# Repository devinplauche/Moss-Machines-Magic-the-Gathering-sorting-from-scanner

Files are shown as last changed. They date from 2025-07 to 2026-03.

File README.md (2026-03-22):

# Moss Machine - Open Source Magic: The Gathering - MTG - Sorting & Recognition

<p align="center">
  
</p>

Welcome to the Moss Machine project! This open-source initiative provides a comprehensive system for automating the sorting, recognition, and management of Trading Card Game (TCG) cards.

Current runtime note: `Current-version/optimized_scanner.py` is configured for **Magic: The Gathering only**.

Project layout reference: see `docs/PROJECT_STRUCTURE.md` for the permanent vs one-time script organization.

---

### Overview

The Moss Machine combines perceptual hash-based computer vision, multi-threaded processing, and hardware integration to create a high-performance, scalable card sorting solution. Whether you're a collector, player, or developer, this project offers tools and guidance to build your own automated card sorting system with speeds capable of processing cards in under 2 seconds per scan.

---

## Features

- **Open Source & Community Driven**  
  Fully open source code with transparent development. Contributions and modifications are encouraged—please credit the original source when creating derivatives.

- **Multi-Game Support**  
  - Supports **317 different trading card games** from a unified SQLite database
  - Includes Magic: The Gathering, Pokemon, Yu-Gi-Oh!, Flesh and Blood, Lorcana, and 300+ more
  - Filterable by game, set, rarity, and foil type for precise scanning
  - Automatic database download from server if not found locally

- **High-Performance Recognition Engine**  
  - **Perceptual hashing (pHash)** with 256-bit hash using 16x16 hash size for robust image matching
  - **RGB channel separation** - computes separate hashes for Red, Green, and Blue channels for improved accuracy
  - **Multi-threaded scanning** - parallel processing across games with 8 worker threads by default
  - **Early termination** - stops scanning immediately when exact match (distance = 0) is found
  - **Hash caching** - optional in-memory cache for popular games (Magic, Pokemon, Yu-Gi-Oh) for faster repeat scans
  - **Adaptive threshold scanning** - progressive tightening from strict to relaxed thresholds
  - **Quick distance pre-filtering** - rejects bad matches early using single-channel checks
  - **Hamming distance** calculation for fast hash comparison
  - **Average scan time** -: ~2 seconds per card across 317 games

- **Advanced Image Processing**  
  - **OpenCV-based** card detection with contour finding and perspective correction
  - **Automatic card orientation** - handles cards at any angle with 4-point perspective transform
  - **Region-based hashing** - uses top-left 745x745px crop for consistent hash generation
  - **VL6180X ToF sensor integration** - hardware distance sensing for precise Z-axis control during pickup/release
  - **Real-time camera feed processing** with automatic card detection

- **Flexible Sorting Modes**  
  - **Color sorting** - White, Blue, Black, Red, Green, Multicolor, Colorless, Land (Basic/Nonbasic)
  - **Mana value (CMC)** - Bins from 1-8+ with overflow handling
  - **Set code** - Sort by expansion/set with token detection
  - **Price-based** - 14 price brackets from $0.02 to $128+ with configurable thresholds
  - **Card type** - Creature, Artifact, Enchantment, Instant, Sorcery, Planeswalker, Battle, Land, Token
  - **Alphabetical (A-Z)** - First letter sorting with 0-9 bin for numbers/symbols
  - **Rarity** - Common, Uncommon, Rare, Mythic, Special, Bonus, Promo
  - **Finish** - Foil, Nonfoil, Both (for cards with multiple finishes)
  - **Buy mode** - Custom price threshold for purchase evaluation

- **Hardware Integration**  
  - **Arduino Mega control** via serial communication (PySerial)
  - **3-axis stepper motor control** (X, Y, Z axes plus dual E-motors for coordinated movement)
  - **Endstop sensors** on all 6 positions (X/Y/Z min/max) for safety and homing
  - **Dual vacuum system** - separate pickup and release control
  - **LED lighting control** for optimal camera visibility
  - **16x2 LCD display** (I2C) for real-time machine status
  - **34-tray sorting system** with configurable tray assignments
  - **Automatic homing and calibration** with configurable course correction
  - **Overflow tray (34)** and reject bin (33) with automatic routing
  - **Configurable parameters**: pickup/drop distances, movement speeds, thresholds, calibration multipliers
  - **Safety features**: endstop monitoring, retry logic (10 attempts), timeout handling
  - **Start/Stop machine states** - prevents accidental movements during parameter changes

- **GUI Control Interface**  
  - **Enhanced Tkinter GUI** with tabbed interface (Scanner, Arduino, Export)
  - **Live camera feed** display with real-time card detection overlay
  - **Manual and auto-scan modes** with configurable cooldown
  - **Arduino monitoring** - real-time sensor data display (range, endstops, motor states)
  - **Motor control panel** - manual control of X, Y, Z, E0, E1 motors
  - **Parameter upload/fetch** - live parameter editing and synchronization
  - **CSV export** - scan history with auto-export option
  - **Inventory tracking** - reject duplicate cards automatically
  - **Game/Set/Rarity/Foil filters** with dropdown selection
  - **Status logging** with color-coded messages

- **Performance & Reliability**  
  - **Detailed statistics** - tracks scans, total time, average time, cards checked, cache hits
  - **Retry mechanisms** - up to 10 pickup attempts with distance sensor verification
  - **Periodic homing** - automatic recalibration every N cards (configurable)
  - **Course correction** - fine-tune X/Y positioning to prevent drift
  - **Thread-local database connections** for safe multi-threading
  - **Confidence scoring** - percentage-based match quality with configurable minimum thresholds
  - **Duplicate detection** via inventory file tracking

- **Command Line Interface**  
  - Interactive mode with sorting menu
  - Realtime webcam mode for continuous scanning
  - Single-image scanning with detailed match output
  - Game/set/rarity/foil filtering via command-line arguments
  - List all games, sets, rarities, and foil types
  - Adjustable threshold and top-N results
  - Cache preloading option
  - Serial port and baud rate configuration

- **Configurable & Extensible**  
  - All movement parameters configurable (speeds, distances, calibration multipliers)
  - Adjustable hash matching thresholds (default: 10, lower = stricter)
  - Customizable tray assignments with automatic overflow
  - Price threshold configuration for buy mode
  - Worker thread count adjustable (default: 8)
  - Scan cooldown adjustable (default: 2.0 seconds)
  - Game-specific foil type and rarity detection

- **Technology Stack**  
  - **Python 3**: OpenCV (cv2), ImageHash, Pillow (PIL), PySerial, NumPy, SQLite3, Threading, Tkinter
  - **Database**: Unified SQLite database with 317 game-specific card tables, games table, sets table, and others (future development)
  - **Arduino**: C++ firmware for Mega 2560, Stepper motor control, I2C LCD, VL6180X ToF sensor (Adafruit library)
  - **Hardware**: RAMPS 1.4 board, A4988 stepper drivers, NEMA 17 motors, endstop switches, vacuum pumps, LED strips  

---

## System Architecture

### Software Components

1. **optimized_scanner.py** - Core recognition engine
   - `OptimizedCardScanner` class with multi-threaded game scanning
   - Perceptual hash computation and comparison
   - Database connection pooling (thread-local connections)
   - Adaptive threshold scanning
   - Serial communication with Arduino
   - Real-time webcam mode
   - Command-line interface with extensive filtering options

2. **gui_interface_enhanced.py** - GUI control interface
   - Tabbed interface (Scanner, Arduino, Export)
   - Live camera feed with card detection visualization
   - Arduino parameter management and monitoring
   - CSV export with scan history
   - Game/Set/Rarity/Foil filtering
   - Auto-scan and manual scan modes

3. **Main.ino** - Arduino firmware
   - 3-axis stepper motor control (X, Y, Z + E0, E1 dual drive)
   - VL6180X ToF sensor integration for distance measurement
   - Endstop monitoring (6 endstops: X/Y/Z min/max)
   - Dual vacuum system control
   - LCD status display (16x2 I2C)
   - Serial command parser with start/end markers
   - 34-tray coordinate system with automatic routing
   - Homing and calibration routines
   - State machine (Stopped/Started) for safe operation

### Database Structure

- **unified_card_database.db** (SQLite)
  - `games` table: 317 games with ID, name, display_name, total_cards
  - `cards_*` tables: One table per game (e.g., cards_magic, cards_pokemon, cards_yugioh)
  - `sets` table: Set information per game with set codes and card counts
  - Card columns: unique_id, product_id, set_code, rarity, name, series, number, prices (low/mid/high/market/imputed), subTypeName (foil type), has_image, phash (r_phash, g_phash, b_phash), extCardType
  - Optional: SKU columns (111 columns for condition/language/printing combinations)

### Hardware Components

- **Arduino Mega 2560** - Main controller
- **RAMPS 1.4** - Motor driver board
- **A4988 Stepper Drivers** (5x) - Motor control
- **NEMA 17 Stepper Motors** (5x) - X, Y, Z, E0, E1 axes
- **VL6180X ToF Sensor** - Distance measurement (I2C)
- **Endstop Switches** (6x) - Limit switches for safety
- **16x2 LCD Display** (I2C) - Status display
- **Vacuum Pumps** (2x) - Card pickup and release
- **LED Strip** - Lighting for camera
- **Webcam** - Card image capture

---

## Quick Start

### Software Setup

1. **Install Python dependencies:**
   ```bash
   pip install opencv-python pillow imagehash pyserial numpy
   ```

2. **Database:**
   - Place `unified_card_database.db` in the project directory
   - Or let the scanner auto-download from configured server URLs

3. **Run the scanner:**
   ```bash
   # Command-line mode (single image)
   python optimized_scanner.py card.jpg --cache

   # Interactive mode with Arduino
   python optimized_scanner.py --interactive --serial-port COM3

   # Realtime webcam mode
   python optimized_scanner.py --realtime --cache

   # GUI mode
   python gui_interface_enhanced.py
   ```

### Arduino Setup

1. **Install Arduino libraries:**
   - LiquidCrystal_I2C
   - Adafruit_VL6180X
   - Wire (built-in)
   - Stepper (built-in)

2. **Upload Main.ino** to Arduino Mega 2560

3. **Connect hardware:**
   - RAMPS 1.4 to Mega
   - Stepper motors to X, Y, Z, E0, E1 outputs
   - Endstops to min/max pins
   - VL6180X sensor to I2C (SDA/SCL)
   - LCD to I2C
   - Vacuum relays to pins 9 & 10
   - LED to pin 8

4. **Configure serial port** in Python scripts (default: COM3, 9600 baud)

### Usage Examples

```bash
# List all supported games
python optimized_scanner.py --list-games

# List sets for Magic (game ID 167)
python optimized_scanner.py --list-sets 167

# Scan a card, filter to Magic only
python optimized_scanner.py card.jpg -g Magic --cache

# Scan with set filter (Alpha and Beta)
python optimized_scanner.py card.jpg -s LEA -s LEB

# Filter by foil type and rarity
python optimized_scanner.py card.jpg -f Foil -r M -r R

# Adaptive scan with relaxed thresholds
python optimized_scanner.py card.jpg -t 20 --min-confidence 70
```

---

## Configuration

### Scanner Parameters (optimized_scanner.py)

- `max_workers`: Thread pool size (default: 8)
- `cache_enabled`: Enable in-memory hash caching (default: True)
- `threshold`: Match threshold, lower = stricter (default: 10)
- `top_n`: Number of top matches to return (default: 10)
- `min_confidence`: Minimum confidence % for Method 1 (default: 85.0)
- `scan_cooldown`: Seconds between auto-scans (default: 2.0)

### Arduino Parameters (Main.ino)

- `Xcal`, `Ycal`, `Zcal`: Movement calibration multipliers (350, 475, 140)
- `speed`: XY movement speed in microseconds (default: 700)
- `zspeed`, `zespeed`: Z-axis speeds (75, 120)
- `initial_pickup_distance`: Z distance to pickup position (6000 steps)
- `initial_drop_distance`: Z distance to drop position (4000 steps)
- `pickup_threshold`: Distance threshold for successful pickup (40mm)
- `release_threshold`: Distance threshold for successful release (40mm)
- `HCC`: Homing cycle count - rehome every N cards (default: 10)
- `XCourseCorrection`, `YCourseCorrection`: Fine-tune positioning (0, 1)

### Tray Layout (Main.ino)

- **Trays 1-32**: Configurable card bins
- **Tray 33**: RejectCard bin (reserved)
- **Tray 34**: OverflowTray (reserved)
- Coordinate arrays: `X[6][5]` and `Y[4][7]` define physical tray positions

---

## Pictures


---

### Disclaimer

- The project is open source and may evolve significantly over time.  
- All code is thoroughly tested but may require calibration based on your hardware setup.  
- Use caution—never put valuable cards in the machine without testing.  
- If you modify or create your own variations, please credit the original source.

---

## Build Your Own

### Get Started
- All necessary files, including code, 3D print files, and hardware schematics, are available in this repository.
- Follow the detailed instructions within the Discord under #assembly

---

## Legal & Usage Notice

**Disclaimer:**  
This system is intended for hobbyist and educational use. Always test with non-valuable cards first. Handle valuable or rare cards with care—never trust automated sorting in critical scenarios. The project is open source; use at your own risk.

---

## Connect with Us & Follow

| Discord Logo | Reddit Logo | GitHub Logo |
|:---:|:---:|:---:|
| **Join our Discord:**<br>[https://discord.gg/2gNWpV6UjW](https://discord.gg/2gNWpV6UjW) | **Reddit:**<br>[r/MossMachine](https://www.reddit.com/r/MossMachine/) | **Repository:**<br>[GitHub](https://github.com/KairiCollections/Moss-Machine---Magic-the-Gathering-recognition-and-sorting-machine) |

---

## Support
Help keep my motivation and my wife less annoyed with the machine's existence
- Patreon - https://www.patreon.com/KairiCollections
- By me a coffee - https://www.buymeacoffee.com/KairiCollections
- Ko-fi - http://ko-fi.com/kairiskyewillow

Other non-related support:
- https://www.etsy.com/shop/KairiCollections

---

## Acknowledgments & License

This project is licensed under the **Creative Commons Attribution-NonCommercial-ShareAlike 4.0 International License (CC BY-NC-SA 4.0)**.  
Please give credit to the original authors when creating derivatives.

---

**Happy Sorting!**

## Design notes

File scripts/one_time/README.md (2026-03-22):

# One-time Scripts

This folder contains scripts and artifacts used for manual debugging, migration, and investigation.

These files are intentionally separated from runtime scanner code so junior engineers can quickly identify what is safe to run in production flows.

Current contents:

- `check_db.py`
- `check_real_db.py`
- `debug_hisokas.py`
- `explore_db.py`
- `debug_scan_with_custom.json`
- `debug_scan_without_custom.json`

Guideline:

- If a script is only used for a one-off task or local debugging, place it here.
- If a script is imported by runtime code or CI tests, keep it in a permanent runtime location.

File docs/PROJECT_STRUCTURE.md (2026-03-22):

# Project Structure

This repository is organized by runtime permanence and ownership.

## Core Runtime (Permanent)

- `Current-version/optimized_scanner.py`: Main scanner runtime and CLI.
- `Current-version/scanner_modules/image_preprocessing.py`: Image-path validation and reusable crop/warp helpers.
- `Current-version/card_filter.py`: Metadata pre-filtering logic.
- `Current-version/card_collection_manager.py`: Collection persistence/export.
- `Current-version/gui_interface_enhanced.py`: GUI controller and scanner orchestration.
- `Current-version/plugins/`: Runtime plugin interfaces and stubs.
- `Current-version/recognition_data/`: pHash databases and scan metadata assets.

## Test Suite (Permanent)

- `test_debug_crops_regression.py`: Regression tests for missing-file behavior, debug crop names, and `IMG_3490.jpg` handling.
- `test_card_filter.py`, `test_hisokas.py`, `test_scanner.py`, `test_system_complete.py`: Existing tests and integration checks.

## One-time and Exploratory Assets

- `scripts/one_time/`: ad hoc scripts and JSON snapshots used for investigation or manual maintenance.
- `Current-version/ai-slop/`: one-off data generation, diagnostics, and historical pHash maintenance scripts.

## Working Data

- `Collection/`: scanner input/output artifacts.
- `Current-version/debug_crops/`: diagnostic crops used for scanner regression and tuning.

## Naming and Placement Rules

- Put runtime logic used by scanner/GUI in `Current-version/`.
- Put reusable helpers in `Current-version/scanner_modules/`.
- Put throwaway scripts or migration jobs in `scripts/one_time/`.
- Add or update tests in the repository root as `test_*.py`.

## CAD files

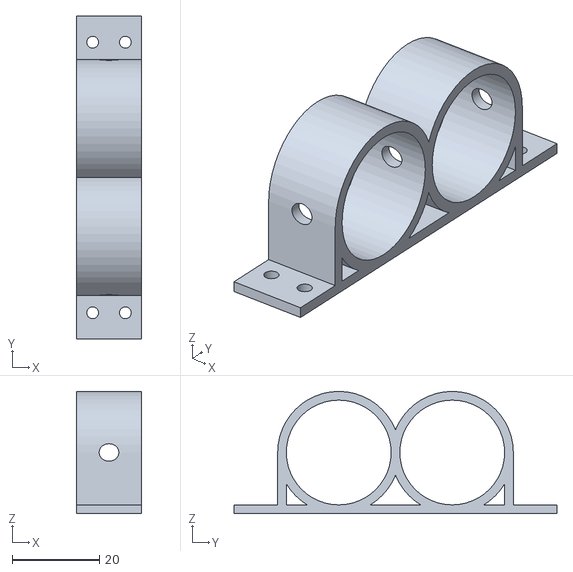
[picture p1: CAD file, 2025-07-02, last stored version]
3D print/Electrical/Din rail options/Double vacuum mount.stl
15.0 x 74.0 x 28.0

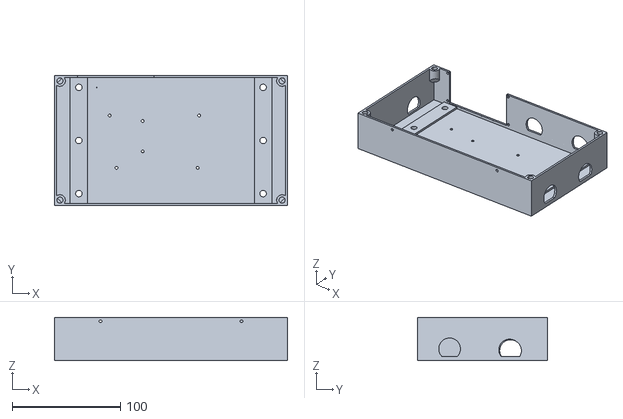
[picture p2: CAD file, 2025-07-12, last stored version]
3D print/Electrical/Electrical box/Electrical box.stl
215.0 x 120.0 x 39.8

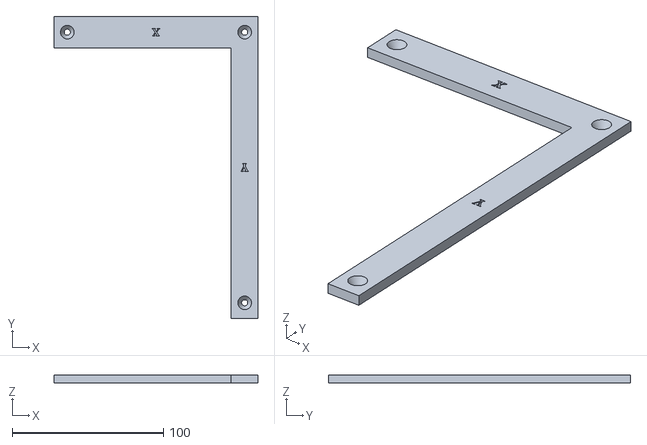
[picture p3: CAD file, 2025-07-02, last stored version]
3D print/Trays/Corner 3.stl
135.0 x 200.0 x 5.00

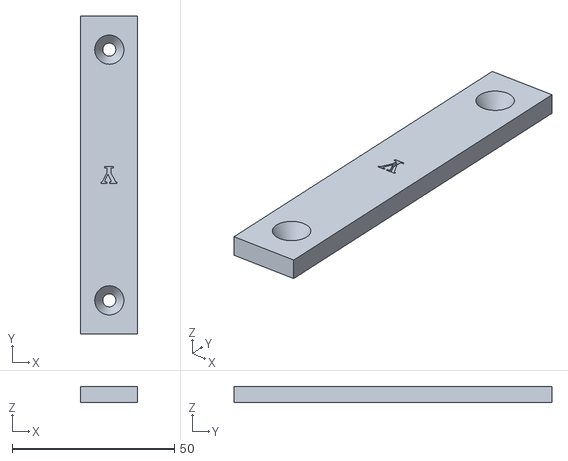
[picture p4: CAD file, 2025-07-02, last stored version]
3D print/Trays/Y space - Print 2.stl
17.7 x 98.0 x 5.00

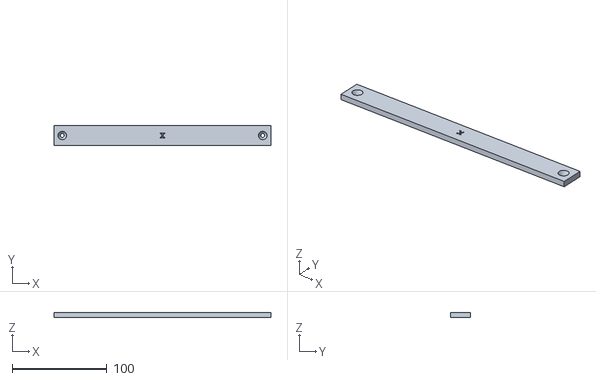
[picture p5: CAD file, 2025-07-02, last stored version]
3D print/Trays/X space - Print 2.stl
229.5 x 20.8 x 5.00

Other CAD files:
3D print/Trays/Corner 2.stl
3D print/Trays/Corner 1.stl
3D print/Trays/Corner 4.stl

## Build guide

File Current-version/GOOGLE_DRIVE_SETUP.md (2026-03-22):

# Google Drive Batch Scanning - Setup & Usage Guide

## Overview

This system integrates Google Drive with the MTG card scanner, allowing you to:
- Authenticate with Google Drive
- List all images in a specified folder
- Download images locally
- Scan each card automatically
- Export results to CSV/JSON

## Prerequisites

### 1. Install Required Python Packages

```bash
pip install google-auth-oauthlib google-auth-httplib2 google-api-python-client
```

### 2. Set Up Google Drive API Credentials

#### Step 1: Create a Google Cloud Project
1. Visit [Google Cloud Console](https://console.cloud.google.com/)
2. Create a new project or select an existing one
3. Enable the **Google Drive API**:
   - Click "APIs & Services" → "Library"
   - Search for "Google Drive API"
   - Click it and press "Enable"

#### Step 2: Create OAuth 2.0 Credentials
1. Go to "APIs & Services" → "Credentials"
2. Click "Create Credentials" → "OAuth 2.0 Client ID"
3. Choose "Desktop application"
4. Click "Create"
5. Click the download icon (appears when hovering over your credential)
6. Save the file as `credentials.json` in the `Current-version/` directory

#### Step 3: First Run Authentication
The first time you run a scan command, it will:
1. Open a browser window asking for Google Drive access
2. Create a local token file (`google_drive_token.pickle`) for future use
3. Proceed with scanning

## Quick Start

### Basic Usage

```bash
cd Current-version
python scan_google_drive.py --folder-url "https://drive.google.com/drive/folders/1g_WOPFaYGWfiKbtLqO3aZAOEQOWnxJLc"
```

### With Output Files

```bash
python scan_google_drive.py \
    --folder-url "https://drive.google.com/drive/folders/1g_WOPFaYGWfiKbtLqO3aZAOEQOWnxJLc" \
    --output-csv scan_results.csv \
    --output-json scan_results.json
```

### Keep Downloaded Images

```bash
python scan_google_drive.py \
    --folder-url "1g_WOPFaYGWfiKbtLqO3aZAOEQOWnxJLc" \
    --keep-local
```

### Using Filters

```bash
python scan_google_drive.py \
    --folder-url "1g_WOPFaYGWfiKbtLqO3aZAOEQOWnxJLc" \
    --set-filter "MIR" \
    --foil-filter "Non Foil" \
    --output-csv results.csv
```

## Command Line Options

```
--folder-url URL              Google Drive folder URL or folder ID [REQUIRED]
--threshold N                 Match threshold, 0-255 (default: 40, lower = stricter)
--top-n N                     Number of top matches to return (default: 10)
--output-csv PATH             Save results as CSV file
--output-json PATH            Save results as JSON file
--set-filter CODE             Filter by card set code (e.g., "MIR", "TSR")
--foil-filter TYPE            Filter by foil type (e.g., "Foil", "Non Foil")
--rarity-filter RARITY        Filter by rarity (e.g., "Rare", "Uncommon")
--download-dir PATH           Directory for downloaded images (default: google_drive_downloads)
--keep-local                  Keep downloaded images after scanning (default: delete)
--force-reauth                Force re-authentication to Google Drive
--max-workers N               Parallel workers for processing (default: 4)
--db-path PATH                Path to card database (default: unified_card_database.db)
--verbose                     Verbose output
--help                        Show all options
```

## Python API Usage

If you want to integrate this into your own Python code:

```python
from optimized_scanner import OptimizedCardScanner
from google_drive_scanner import BatchGoogleDriveScanner

# Initialize scanner
scanner = OptimizedCardScanner()

# Initialize batch processor
batch = BatchGoogleDriveScanner(scanner, download_dir="my_downloads")

# Force authentication on first run
# batch.gdrive_client.authenticate()

# Scan folder
folder_url = "https://drive.google.com/drive/folders/1g_WOPFaYGWfiKbtLqO3aZAOEQOWnxJLc"
results, stats = batch.scan_folder(
    folder_url_or_id=folder_url,
    threshold=40,
    output_csv="results.csv",
    output_json="results.json",
    keep_local_copies=False
)

# Access results
for result in results:
    if result.get('match_found'):
        print(f"Found: {result['card_name']} ({result['set']})")
    else:
        print(f"No match: {result['source_file']}")

# Access stats
print(f"Matches found: {stats['matches_found']} / {stats['processed']}")
```

## Output Format

### CSV Results
Columns include:
- `source_file`: Original filename from Google Drive
- `card_name`: Recognized card name
- `set`: Card set code
- `product_id`: Product ID from database
- `distance`: Hash distance (0 = exact match)
- `confidence`: Confidence percentage (0-100)
- `rarity`: Card rarity
- `foil_type`: Foil type (Foil/Non-Foil/etc)
- `number`: Card number in set
- `status`: success/error
- `all_matches`: Top 3 matching cards (JSON)

### JSON Results
```json
{
  "timestamp": "2026-03-21 14:30:45",
  "results": [
    {
      "source_file": "scan_001.jpg",
      "card_name": "Black Lotus",
      "set": "BET",
      "distance": 0,
      "confidence": 100.0,
      "status": "success"
    }
  ],
  "stats": {
    "total_files": 50,
    "successful_scans": 48,
    "matches_found": 42
  }
}
```

## Troubleshooting

### Authentication Issues

**Q: "Credentials file not found"**
- Make sure `credentials.json` is in the `Current-version/` directory
- See setup step 2 above for how to download credentials

**Q: "Token refresh failed"**
- Delete `google_drive_token.pickle` and run with `--force-reauth`
- You'll need to re-authenticate in the browser

### Scanning Issues

**Q: "No images found in folder"**
- Verify the folder URL/ID is correct
- Ensure the folder actually contains image files (jpg, png, bmp, etc)
- Check that sharing permissions allow your account to view the folder

**Q: "Downloaded image can't be scanned"**
- Verify the image is a valid card photo
- Try reducing the `--threshold` value for more lenient matching
- Check that the database file exists: `unified_card_database.db`

**Q: "Process is slow"**
- Increase `--max-workers` (be careful not to exceed API rate limits)
- Use `--set-filter` to narrow down the search space
- Consider reducing `--top-n` if you only need 1-2 matches

### Google Drive API Issues

**Q: "Rate limit exceeded"**
- Wait a few minutes before running again
- Reduce `--max-workers` to lower concurrency
- Google Drive API has strict rate limiting for free accounts

**Q: "Permission denied"**
- Verify you have access to the Google Drive folder
- Try removing `google_drive_token.pickle` and re-authenticating
- Check Google Cloud Console project permissions

## Advanced Usage

### Batch Processing Multiple Folders

```bash
#!/bin/bash
# Process multiple folders
for folder_id in "1g_WOPFaYGWfiKbtLqO3aZAOEQOWnxJLc" "2h_XXXxxxGWfiKbtLqO3aZAOEQOWnxJLd"; do
  python scan_google_drive.py \
    --folder-url "$folder_id" \
    --output-csv "results_${folder_id}.csv"
done
```

### Combining Results

```python
import pandas as pd
import glob

# Combine all CSV results
all_results = []
for csv_file in glob.glob("results_*.csv"):
    df = pd.read_csv(csv_file)
    all_results.append(df)

combined = pd.concat(all_results, ignore_index=True)
combined.to_csv("all_results_combined.csv", index=False)
print(f"Total cards scanned: {len(combined)}")
print(f"Matches found: {combined[combined['match_found'] == True].shape[0]}")
```

## Performance Tips

1. **Threshold Tuning**: 
   - Lower values (10-30): Stricter matching, fewer false positives
   - Higher values (60-100): More lenient, better for low-quality images

2. **Parallel Processing**:
   - Default `--max-workers 4` is usually safe
   - Increase to 8-16 for VPS/server environments
   - Keep ≤4 for local machines to avoid resource exhaustion

3. **Filtering**:
   - Use `--set-filter` when scanning specific sets
   - Dramatically speeds up search when you know the set

4. **Network**:
   - Faster internet = faster downloads
   - Run on same network as scanner if possible

## Support

For issues or questions:
1. Check the troubleshooting section above
2. Run with `--verbose` for detailed output
3. Check that all dependencies are installed: `pip list | grep google`

## Files

- `google_drive_scanner.py`: Core Google Drive integration library
- `scan_google_drive.py`: CLI command-line interface
- `credentials.json`: Your Google Drive API credentials (create in setup)
- `google_drive_token.pickle`: Cached authentication token (auto-created)
- `google_drive_downloads/`: Directory where images are downloaded (default)

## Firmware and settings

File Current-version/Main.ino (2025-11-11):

#include <LiquidCrystal_I2C.h>
#include <Stepper.h>
#include <Wire.h>
#include "Adafruit_VL6180X.h"

//Pin Definitions for hardware control
enum Pins { 
    Zmin = 18, Xmin = 3, Ymin = 14, Xmax = 2, Ymax = 15, Zmax = 19, //Endstops
    Lights = 8, Vacuum1 = 9, Vacuum2 = 10, //Vacuums: Pickup/Release respectively
    Xenable = 38, Yenable = 56, Zenable = 62, E0enable = 24, E1enable = 30, //Motors
    Xstep = 54, Ystep = 60, Zstep = 46, E0step = 26, E1step = 36, //Stepper Controls
    Xdir = 55, Ydir = 61, Zdir = 48, E0dir = 28, E1dir = 34 //Directions
};

//Initialize sensor and display objects
Adafruit_VL6180X vl = Adafruit_VL6180X();  //VL6180X distance sensor object
LiquidCrystal_I2C lcd(0x27, 16, 2);        //LCD for user feedback

//Flags and control variables
boolean newData = false, readInProgress = false, newDataFromPC = false;
boolean atHomePosition = true;  //Track if machine is at home position (safe for parameter changes)
boolean machineStarted = false; //Track if machine is in Started state (accepting tray commands)
byte bytesRecvd = 0, PickupRetry;
const byte numChars = 64, buffSize = 40;                                               //Buffer sizes for serial communication
const char startMarker = '<', endMarker = '>';                                         //Start/End markers for data communication
char inputBuffer[buffSize], messageFromPC[buffSize] = { 0 }, receivedChars[numChars];  //Buffers for data

//Timers and counters
float timeoutcount = 0;
const float timeout = 10;

//Coordinates and distance tracking arrays
const char* MatchingValues[] = {"RejectCard", "tray1", "tray7", "tray14", "tray18","tray25", "tray26", "tray27", "tray28", "tray29", "tray30", "tray31", "tray32"};
const int loopStart[] = {33, 1, 7, 14, 18, 25, 26, 27, 28, 29, 30, 31, 32};
const int loopEnd[] = {33, 6, 13, 17, 24, 25, 26, 27, 28, 29, 30, 31, 32};
boolean match = 0;
const int xOffsets[6] = {-3, -2, -1, 1, 2, 3}; const int yOffsets[4] = {-2, -1, 1, 2}; //Arrays for X/Y coordinate movements
const short X[6][5]={{31,27,21,28,32},{23,11,9,12,24},{17,5,1,6,18},{19,7,2,8,20},{25,13,10,14,26},{33,29,22,30,34}}; //Array for X trays
const short Y[4][7]={{32,24,18,16,20,26,34},{28,12,6,4,8,14,30},{27,11,5,3,7,13,29},{31,23,17,15,19,25,33}}; //Array for Y trays
short CountArray[35], upcount; //Array is for keeping track of how many cards have been moved to each tray
String AssignedTrayValue[35], Tempval1; //Array for keeping try of tray assignments
uint8_t range[6]; //Range readings from VL6180X sensor

//Endstop tracking variables (limits of movement for each axis)
byte X_ENDSTOP_MIN, Y_ENDSTOP_MIN, Z_ENDSTOP_MIN, X_ENDSTOP_MAX, Y_ENDSTOP_MAX, Z_ENDSTOP_MAX;

//Movement parameters (calibration and speed settings)
short initial_pickup_distance = 6000, initial_drop_distance = 4000;  //Intial movement distances
short Xcal = 350, Ycal = 475, Zcal = 140;                            //Movement multipliers
short speed = 700, zspeed = 75, zespeed = 120;                       //Movement speed (Higher number=slower speed)
short pickup_threshold = 40, release_threshold = 40;                 //Thresholds for pickup/release conditions
short HCC = 10, YCourseCorrection = 1, XCourseCorrection = 0;        //Cycles until rehome and course correction variables

void setup() {
  byte pins[] = { Xstep, Ystep, Zstep, E0step, E1step, Xdir, Ydir, Zdir, E0dir, E1dir, Xenable, Yenable, Zenable, E0enable, E1enable, Vacuum1, Vacuum2, Lights};
  for (byte pin : pins) { pinMode(pin, OUTPUT); }  //Set all pins as outputs
  
  // Motors enabled (LOW), vacuums off (LOW), lights ON (HIGH) by default
  digitalWrite(Xenable, LOW);    //X motor enabled
  digitalWrite(Yenable, LOW);    //Y motor enabled  
  digitalWrite(Zenable, LOW);    //Z motor enabled
  digitalWrite(E0enable, LOW);   //E0 motor enabled
  digitalWrite(E1enable, LOW);   //E1 motor enabled
  digitalWrite(Vacuum1, LOW);    //Vacuum1 off
  digitalWrite(Vacuum2, LOW);    //Vacuum2 off
  digitalWrite(Lights, HIGH);    //Lights on by default

  Serial.begin(9600);                        //Begin serial connection
  digitalWrite(13, HIGH);                    //Turn on the onboard LED for debugging
  while (!Serial) { delay(10); }             //Wait for serial to be ready
  Serial.println("Adafruit VL6180x test!");  //Print sensor initialization message
  while (!vl.begin()) {
    Serial.println("Failed to find sensor");
    PrintLCD("Failed to find ", "ToF sensor"); //Display error on LCD if sensor not found
    delay(1000);
  }  
  Serial.println("Sensor found!");PrintLCD("ToF sensor", "found");
  Homemachine(); //Call Homemachine to calibrate the system
  delay(100);Serial.println("<Arduino is ready>");
}

void loop() {
  uint8_t status = vl.readRangeStatus();
  if (AssignedTrayValue[34] != "OverflowTray") {AssignedTrayValue[34] = "OverflowTray";} //Assign some initial tray values that are reserved
  if (AssignedTrayValue[33] != "RejectCard") {AssignedTrayValue[33] = "RejectCard";}
  getDataFromPC(); //Retrieve data from PC

  //Check sensor error status and handle errors accordingly
  if (status == VL6180X_ERROR_NONE) {ReadRange(1); Serial.print("Range: "); Serial.println((range[0] + range[1]) / 2);
  } else {PrintLCD("ToF: No range", " ");}
  switch (status) { //Various errors that can happen with the range sensor
    case VL6180X_ERROR_SYSERR_1 ... VL6180X_ERROR_SYSERR_5: Serial.println("System error"); break;
    case VL6180X_ERROR_ECEFAIL: Serial.println("ECE failure"); PrintLCD("ECE failure", " ");break;
    case VL6180X_ERROR_NOCONVERGE: Serial.println("No convergence"); PrintLCD("No convergence", " "); break;
    case VL6180X_ERROR_RANGEIGNORE: Serial.println("Ignoring range"); PrintLCD("Ignoring range", " "); break;
    case VL6180X_ERROR_SNR: Serial.println("Signal/Noise error"); PrintLCD("Signal/Noise", "error"); break;
    case VL6180X_ERROR_RAWUFLOW: Serial.println("Raw reading underflow"); PrintLCD("Raw reading", "underflow"); break;
    case VL6180X_ERROR_RAWOFLOW: Serial.println("Raw reading overflow"); PrintLCD("Raw reading", "overflow"); break;
    case VL6180X_ERROR_RANGEUFLOW: Serial.println("Range reading underflow"); PrintLCD("Range reading", "underflow"); break;
    case VL6180X_ERROR_RANGEOFLOW: Serial.println("Range reading overflow"); PrintLCD("Range reading", "overflow"); break;
    default: break;
  }
  lcd.init();lcd.backlight();lcd.setCursor(0, 0); //Initialize LCD and turn on the backlight
  ReadEndstops(); //Read endstop values 
  //if(Y_ENDSTOP_MIN==0||Z_ENDSTOP_MIN==0||X_ENDSTOP_MAX==0){PrintLCD("Endstop reached"," ");STOP==1;delay(100);}
  PrintLCD("Ready", " "); //Display "Ready" message on LCD 
  Tempval1 = Serial.readString();delay(10); //read any available data from the serial buffer
  if (Tempval1 != "") {
    PrintLCD("Received: ", Tempval1); //Display the received data on the LCD
    ReadRange(1);DetermineAction(); //Decide what action to take based on received data
    Serial.println("<Arduino is ready>");
    timeoutcount = 0; //Reset timeout counter
  }  
  //timeoutcount++;if(timeoutcount>=timeout){Tray(34);Serial.println("<Arduino is ready>");timeoutcount=0;}
  //Serial.println(timeoutcount);

  //Reset flags
  Tempval1 = "";messageFromPC == "";bytesRecvd == 0;newData = false;readInProgress = false;newDataFromPC = false;
}  

void getDataFromPC() {
  if (Serial.available() > 0) {
    char x = Serial.read();  //Read incoming character
    if (x == endMarker) { //End marker received
      readInProgress = false;
      newDataFromPC = true;
      inputBuffer[bytesRecvd] = 0; //null terminate input buffer 
      parseData(); //parse the received data
    }   
    if (readInProgress) {
      inputBuffer[bytesRecvd] = x;
      bytesRecvd++;  //Data is still being read
      if (bytesRecvd == buffSize) { bytesRecvd = buffSize - 1; } //Prevent buffer overflow
    }  
    if (x == startMarker) { //Start marker received, begin reading
      bytesRecvd = 0;
      readInProgress = true;
    }
  }
}  

//Parse the received data from the buffer
void parseData() {
  char* strtokIndx;
  strtokIndx = strtok(inputBuffer, ",");  //Split the string by commas
  strcpy(messageFromPC, strtokIndx);      //Store the first token
  strtokIndx = strtok(NULL, ",");
  strtokIndx = strtok(NULL, ","); //Continue parsing if necessary
}

//Handle the picking process, with retries
void pick(short steps, byte Release) {PickupRetry = 0;
retrypickup:
  Move1(0, steps, zspeed);  //Move to pickup position
  if (Release == 1) {MotorsOnOff(1);delay(100);digitalWrite(Vacuum2,1);delay(300);digitalWrite(Vacuum2,0);ReadRange(3);  //Turn motors off and release card
    while ((range[2] + range[3]) / 2 < release_threshold) {digitalWrite(Vacuum2,1);delay(300);digitalWrite(Vacuum2,0);ReadRange(3);}//Check range and if card didn't drop retry
    MotorsOnOff(0);delay(100);Move1(1, steps, zespeed);} //Turn motors back on and move back up
  if (Release == 0) {digitalWrite(Vacuum1, 1);delay(500);digitalWrite(Vacuum1, 0);Move1(1, steps, zespeed);}ReadRange(3);//Vacuum to pick up card
    if (((range[2] + range[3]) / 2) > pickup_threshold) {PickupRetry++;if (PickupRetry >= 10) {StopMachine();} else {goto retrypickup;}}//If 10 retrys failed stop the machine
}  

//Homing routine to calibrate the machine
void Homemachine() {PrintLCD("Calibrating", " ");ReadEndstops();  //Read the endstop values
  if (Z_ENDSTOP_MIN == 1) {Move1(0, 800, zespeed);while (Z_ENDSTOP_MIN == 1) {Move1(1, 3, zespeed);Z_ENDSTOP_MIN = digitalRead(Zmin);}delay(200);}//calibrate z
  if (Y_ENDSTOP_MIN == 1) {Move4(1, 0, 0, 50);while (Y_ENDSTOP_MIN == 1) {Move4(0, 1, 0, 5);Y_ENDSTOP_MIN = digitalRead(Ymin);}delay(200);}//calibrate y
  if (X_ENDSTOP_MAX == 1) {Move4(1, 0, 50, 0);while (X_ENDSTOP_MAX == 1) {Move4(0, 1, 3, 0);X_ENDSTOP_MAX = digitalRead(Xmax);}delay(200);}//calibrate x
  Move1(0, 3000, zspeed); delay(200);Move4(1, 0, Xcal * 3 + 55, Ycal * 2 + 38); delay(200); //Move to home position
}  

void StopMachine() { //Stop the machine and display a message
  PrintLCD("Machine stop", "Empty and reset"); MotorsOnOff(0); while (1) { delay(10000);}
}

void ReadEndstops() { //Read the endstop sensors
  X_ENDSTOP_MIN = digitalRead(Xmin);X_ENDSTOP_MAX = digitalRead(Xmax);
  Y_ENDSTOP_MIN = digitalRead(Ymin);Y_ENDSTOP_MAX = digitalRead(Ymax);
  Z_ENDSTOP_MIN = digitalRead(Zmin);Z_ENDSTOP_MAX = digitalRead(Zmax);
}

void MotorsOnOff(boolean OnOff) { //Turns all motors on or off
  digitalWrite(Xenable, OnOff);digitalWrite(E0enable, OnOff);
  digitalWrite(Yenable, OnOff);digitalWrite(E1enable, OnOff);
  digitalWrite(Zenable, OnOff);
}

void DetermineAction() { //Figure out what to do
  // Start/Stop commands
  if (Tempval1 == "StartMachine") {
    machineStarted = true;
    Serial.println("<OK,MachineStarted>");
    PrintLCD("Machine STARTED", "Accepting cards");
    return;
  } else if (Tempval1 == "StopMachine") {
    machineStarted = false;
    Serial.println("<OK,MachineStopped>");
    PrintLCD("Machine STOPPED", "Controls enabled");
    return;
  }
  
  // Tray commands only allowed when machine is started
  for (int i = 0; i < sizeof(MatchingValues) / sizeof(MatchingValues[0]); ++i) {
    if (Tempval1 == MatchingValues[i]) {
      if (!machineStarted) {
        Serial.println("<Error,MachineNotStarted>");
        PrintLCD("Error: Stopped", "Start machine!");
        return;
      }
      match = 1; atHomePosition = false; ForLoop(loopStart[i], loopEnd[i]); atHomePosition = true; 
      break;
    }
  }
  
  // Manual controls only allowed when machine is stopped
  if (Tempval1 == "CalibrateX1" || Tempval1 == "CalibrateX2" || 
      Tempval1 == "CalibrateY1" || Tempval1 == "CalibrateY2" || 
      Tempval1 == "HomeButton") {
    if (machineStarted) {
      Serial.println("<Error,MachineStarted>");
      PrintLCD("Error: Started", "Stop machine!");
      return;
    }
  }
  
  // Calibration commands (minor movements)
  if (Tempval1 == "CalibrateX1") {Move4(0,1,5,0);
  } else if (Tempval1 == "CalibrateX2") {Move4(1,1,5,0);
  } else if (Tempval1 == "CalibrateY1") {Move4(0,0,0,5);
  } else if (Tempval1 == "CalibrateY2") {Move4(0,1,0,5);
  } else if (Tempval1 == "HomeButton") {Homemachine();atHomePosition = true;
  
  // Query sensor data
  } else if (Tempval1 == "QuerySensors") {
    ReadRange(1);
    ReadEndstops();
    String response = "<Sensors,range=";
    response += String((range[0] + range[1]) / 2);
    response += ",xmin=" + String(X_ENDSTOP_MIN);
    response += ",xmax=" + String(X_ENDSTOP_MAX);
    response += ",ymin=" + String(Y_ENDSTOP_MIN);
    response += ",ymax=" + String(Y_ENDSTOP_MAX);
    response += ",zmin=" + String(Z_ENDSTOP_MIN);
    response += ",zmax=" + String(Z_ENDSTOP_MAX);
    response += ",home=" + String(atHomePosition ? 1 : 0);
    response += ",started=" + String(machineStarted ? 1 : 0);
    response += ">";
    Serial.println(response);
  
  // Motor control commands (only when stopped)
  } else if (Tempval1.startsWith("SetMotor,")) {
    if (machineStarted) {
      Serial.println("<Error,MachineStarted>");
      return;
    }
    
    int comma1 = Tempval1.indexOf(',');
    int comma2 = Tempval1.indexOf(',', comma1 + 1);
    String motor = Tempval1.substring(comma1 + 1, comma2);
    int state = Tempval1.substring(comma2 + 1).toInt();
    
    if (motor == "Xenable") digitalWrite(Xenable, state);
    else if (motor == "Yenable") digitalWrite(Yenable, state);
    else if (motor == "Zenable") digitalWrite(Zenable, state);
    else if (motor == "E0enable") digitalWrite(E0enable, state);
    else if (motor == "E1enable") digitalWrite(E1enable, state);
    else if (motor == "Vacuum1") digitalWrite(Vacuum1, state);
    else if (motor == "Vacuum2") digitalWrite(Vacuum2, state);
    else if (motor == "Lights") digitalWrite(Lights, state);
    
    Serial.println("<OK,Motor=" + motor + ",State=" + String(state) + ">");
  
  // Parameter update commands (only allowed at home position AND when stopped)
  } else if (Tempval1.startsWith("SetParam,")) {
    if (machineStarted) {
      Serial.println("<Error,MachineStarted>");
      return;
    }
    if (!atHomePosition) {
      Serial.println("<Error,NotAtHome>");
      return;
    }
    
    int comma1 = Tempval1.indexOf(',');
    int comma2 = Tempval1.indexOf(',', comma1 + 1);
    String param = Tempval1.substring(comma1 + 1, comma2);
    int value = Tempval1.substring(comma2 + 1).toInt();
    
    if (param == "speed") speed = value;
    else if (param == "zspeed") zspeed = value;
    else if (param == "zespeed") zespeed = value;
    else if (param == "xcal") Xcal = value;
    else if (param == "ycal") Ycal = value;
    else if (param == "zcal") Zcal = value;
    else if (param == "pickup_thresh") pickup_threshold = value;
    else if (param == "release_thresh") release_threshold = value;
    else if (param == "hcc") HCC = value;
    else if (param == "ycc") YCourseCorrection = value;
    else if (param == "xcc") XCourseCorrection = value;
    
    Serial.println("<OK,Param=" + param + ",Value=" + String(value) + ">");
  
  // Query current parameters
  } else if (Tempval1 == "QueryParams") {
    String response = "<Params";
    response += ",speed=" + String(speed);
    response += ",zspeed=" + String(zspeed);
    response += ",zespeed=" + String(zespeed);
    response += ",xcal=" + String(Xcal);
    response += ",ycal=" + String(Ycal);
    response += ",zcal=" + String(Zcal);
    response += ",pickup_thresh=" + String(pickup_threshold);
    response += ",release_thresh=" + String(release_threshold);
    response += ",hcc=" + String(HCC);
    response += ",ycc=" + String(YCourseCorrection);
    response += ",xcc=" + String(XCourseCorrection);
    response += ">";
    Serial.println(response);
  
  } else if (match = 1){match = 0;}else{ForLoop(1, 34);} // Handle everything else
}

//Loop through trays and assign values accordingly
void ForLoop(byte first, byte last) {
  for (byte i = first; i <= last; i++) {
    if (AssignedTrayValue[i] == "") {AssignedTrayValue[i] = Tempval1;PrintLCD("Tray assigned ", Tempval1);delay(10);} //if tray assignment is empty assign it the received variable
    if (AssignedTrayValue[i] == Tempval1 && CountArray[i] <= 375) {Tray(i);Serial.println((String) "Went to tray" + i);break;} //if tray assignment equals received value go to that tray and break the loop
    else if (i == 34 && CountArray[34] < 375) {Tray(34);break;} //If loop reaches 34 go to tray 34 if less than 375 cards is in that tray
    else if (i == 34 && CountArray[34] >= 375) {StopMachine();Tempval1 = "";break;} //If loop reaches 34 and has 375 cards or more in it stop the machine
  }
}

//Function to handle the tray action based on the given tray number
void Tray(short var) {
  atHomePosition = false;  //Mark as not at home during tray operation
  Move1(0, initial_pickup_distance, zspeed);ReadRange(1); //Move the Z-axis to the initial pickup position and read the range
  pick((range[0] + range[1]) / 2 * Zcal, 0);upcount++;CountArray[var]++; //Pick the card, Increment the total upcount and tray count
  short x, y;
  //Determine the X and Y coordinates based on the tray number
  for (byte j = 0; j < 6; j++) {if (X[j / 2][j % 4] == var) {x = xOffsets[j];break;}}
  for (byte j = 0; j < 4; j++) {if (Y[j][0] == var) {y = yOffsets[j];break;}}
  int absX = abs(Xcal * x);int absY = abs(Ycal * y);
  int moveToDirectionX =   (x >= 0) ? 1 : 0; int moveToDirectionY =   (y >= 0) ? 0 : 1; Move4(moveToDirectionX,   moveToDirectionY,   absX, absY); // Move to coordinate
  pick(initial_drop_distance, 1); ReadRange(5); while ((range[4] + range[5]) / 2 > 53) {Move1(1,5,zespeed);}
  int moveBackDirectionX = (x >= 0) ? 0 : 1; int moveBackDirectionY = (y >= 0) ? 1 : 0; Move4(moveBackDirectionX, moveBackDirectionY, absX, absY); // Move back to home tray
  Move1(1, initial_pickup_distance, zespeed); //Move Z back up to home position
  if (y != 0) { Move4(0, 0, 0, YCourseCorrection); } if (x != 0) { Move4(0, 1, XCourseCorrection, 0); } //Make course corrections if not 0
  if (upcount % HCC == 0 && upcount >= HCC / 2) { Homemachine(); } //If HCC count reached, rehome the machine
  atHomePosition = true;  //Back at home position
}

//Function to move in 4 directions based on the provided parameters
void Move4(boolean dir1, boolean dir3, short steps1, short steps2) {
  boolean dir2;
  if (dir1 == 0) {dir2 = 1;}else{dir2 = 0;}
  digitalWrite(Xdir, dir1); digitalWrite(E0dir, dir2); digitalWrite(Ydir, dir3); digitalWrite(E1dir, dir3);
  for (short i = 0; (i < steps1 || i < steps2); i++) { //Loop to move for the required number of steps in both directions
    if (i < steps1) {digitalWrite(Xstep, HIGH); digitalWrite(E0step, HIGH);}
    if (i < steps2) {digitalWrite(Ystep, HIGH); digitalWrite(E1step, HIGH);}
    delayMicroseconds(speed);
    digitalWrite(Xstep, LOW); digitalWrite(E0step, LOW); digitalWrite(Ystep, LOW); digitalWrite(E1step, LOW); //Deactivate step pins after each pulse
    delayMicroseconds(speed);
  }
}

//Function to move along the Z-axis with a specified direction and steps
void Move1(boolean dir, short steps, short speed1) {
  digitalWrite(Zdir, dir);
  for (short i = 0; i < steps; i++) { //Loop to perform the movement
    digitalWrite(Zstep, HIGH); delayMicroseconds(speed1);
    digitalWrite(Zstep,  LOW); delayMicroseconds(speed1);
  }
}

//Function to print a message to the LCD screen
void PrintLCD(String var1, String var2) {
  lcd.clear(); lcd.setCursor(0, 0); lcd.print(var1); lcd.setCursor(0, 1); lcd.print(var2);
}

//Function to read range values from the sensor
void ReadRange(byte var1) {
    range[var1 - 1] = vl.readRange(); delay(10); //Read range from sensor
    range[var1] = vl.readRange(); delay(10);//Read range from sensor
}

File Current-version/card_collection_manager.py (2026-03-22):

#!/usr/bin/env python3
"""
Card Collection Manager
Handles saving scanned cards and exporting to multiple formats
Supports both TCGTraders SKU format and TCGPlayer text format
"""
import os
import json
import csv
from datetime import datetime
from pathlib import Path

class CardCollectionManager:
    """Manages scanned card collections with export to multiple formats"""
    
    def __init__(self, collection_dir="Collection"):
        self.collection_dir = Path(collection_dir)
        self.collection_dir.mkdir(exist_ok=True)
        
        # Collection file paths
        self.master_file = self.collection_dir / "master_collection.json"
        self.session_file = self.collection_dir / "current_session.json"
        
        # Load existing collections
        self.master_collection = self._load_collection(self.master_file)
        self.current_session = self._load_collection(self.session_file)
        
        # Statistics
        self.stats = {
            'total_scans': 0,
            'session_scans': 0,
            'games': {}
        }
        self._update_stats()
    
    def _load_collection(self, filepath):
        """Load collection from JSON file"""
        if filepath.exists():
            try:
                with open(filepath, 'r', encoding='utf-8') as f:
                    return json.load(f)
            except Exception as e:
                print(f"[!] Error loading {filepath}: {e}")
        return {'cards': [], 'metadata': {'created': datetime.now().isoformat()}}
    
    def _save_collection(self, collection, filepath):
        """Save collection to JSON file"""
        try:
            collection['metadata']['last_updated'] = datetime.now().isoformat()
            with open(filepath, 'w', encoding='utf-8') as f:
                json.dump(collection, f, indent=2, ensure_ascii=False)
            return True
        except Exception as e:
            print(f"[!] Error saving {filepath}: {e}")
            return False
    
    def _update_stats(self):
        """Update collection statistics"""
        self.stats['total_scans'] = len(self.master_collection.get('cards', []))
        self.stats['session_scans'] = len(self.current_session.get('cards', []))
        
        # Count by game
        for card in self.master_collection.get('cards', []):
            game = card.get('game', 'Unknown')
            self.stats['games'][game] = self.stats['games'].get(game, 0) + 1
    
    def add_card(self, card_info, quantity=1, condition='Near Mint', language='EN', is_foil=False):
        """
        Add a scanned card to the collection
        
        Args:
            card_info: Dictionary with card details from scanner
            quantity: Number of copies scanned
            condition: Card condition (Near Mint, Lightly Played, etc.)
            language: Card language code (EN, JP, FR, etc.)
            is_foil: Whether the card is foil
        """
        # Generate TCGTraders SKU
        product_id = card_info.get('product_id') or card_info.get('UniqueID')
        variant_type = 'GRADE' if condition.startswith('PSA') or condition.startswith('BGS') else 'CONDITION'
        
        # Map condition to short code
        condition_map = {
            'Near Mint': 'NM',
            'Lightly Played': 'LP',
            'Moderately Played': 'MP',
            'Heavily Played': 'HP',
            'Damaged': 'DMG',
            'Mint': 'M'
        }
        
        # Extract grade value if graded
        variant_value = condition_map.get(condition, 'NM')
        if variant_type == 'GRADE':
            # Extract numeric grade (e.g., "PSA 10" -> "10")
            import re
            match = re.search(r'(\d+)', condition)
            variant_value = match.group(1) if match else '10'
        
        # Generate SKU: {product_id}_{variant_value}_{language}_{foil}
        foil_suffix = 'F' if is_foil else 'N'
        sku = f"{product_id}_{variant_value}_{language}_{foil_suffix}"
        
        # Create card entry
        card_entry = {
            'product_id': product_id,
            'sku': sku,
            'name': card_info.get('name') or card_info.get('cardName'),
            'set_code': card_info.get('set_code') or card_info.get('set') or card_info.get('setName'),
            'set_name': card_info.get('setName') or card_info.get('extSet'),
            'game': card_info.get('Game') or card_info.get('game'),
            'rarity': card_info.get('rarity') or card_info.get('extRarity'),
            'number': card_info.get('number') or card_info.get('cardNumber') or card_info.get('extNumber'),
            'quantity': quantity,
            'condition': condition,
            'language': language,
            'is_foil': is_foil,
            'variant_type': variant_type,
            'variant_value': variant_value,
            'price': card_info.get('market_price') or card_info.get('price'),
            'timestamp': datetime.now().isoformat(),
            # Optional scan metadata (used by calibration submissions)
            'scan_image_path': card_info.get('scan_image_path') or card_info.get('scanImagePath'),
            'scan_backend': card_info.get('scan_backend') or card_info.get('backend'),
            'scan_confidence': card_info.get('confidence'),
            'scan_hash': card_info.get('scan_hash')
        }
        
        # Add to both collections
        self.master_collection['cards'].append(card_entry)
        self.current_session['cards'].append(card_entry)
        
        # Update stats
        self.stats['total_scans'] += 1
        self.stats['session_scans'] += 1
        game = card_entry['game']
        self.stats['games'][game] = self.stats['games'].get(game, 0) + 1
        
        # Auto-save
        self._save_collection(self.master_collection, self.master_file)
        self._save_collection(self.current_session, self.session_file)
        
        return card_entry
    
    def export_tcgtraders_csv(self, filename=None, game_filter=None):
        """
        Export collection in TCGTraders CSV format (our website)
        
        Format: Quantity,SKU,Name,Set,Condition,Language
        """
        if filename is None:
            timestamp = datetime.now().strftime('%Y%m%d_%H%M%S')
            filename = self.collection_dir / f"traders_export_{timestamp}.csv"
        
        cards = self.master_collection.get('cards', [])
        
        # Filter by game if specified
        if game_filter:
            cards = [c for c in cards if c.get('game') == game_filter]
        
        try:
            with open(filename, 'w', newline='', encoding='utf-8') as f:
                writer = csv.writer(f)
                
                # Write header - TCGTraders import is strictly on SKU
                writer.writerow(['Quantity', 'SKU'])
                
                # Write cards
                for card in cards:
                    writer.writerow([
                        card.get('quantity', 1),
                        card.get('sku', '')
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

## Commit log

2025-07-02 Removed tiny mounts - Added border frame
    [Corner 1.stl, Corner 2.stl, Corner 3.stl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]
2025-07-02 Changed single vac mount to double vac mount
    [Double vacuum mount.stl, Vacuum mount.stl]
2025-07-04 Update Main8.ino
    Syntax error correction on line 184
    [Main8.ino]
2025-12-29 Fixed a bunch of stuff
    Added a lot of features, fixed a lot of issues. Now communicates with my server for downloading on demand data, at least it SHOULD
    [gui_interface_enhanced.py, optimized_scanner.py]
2026-01-28 Add files via upload
    Fixed some bugs, now works with multiple games and incorporates MSER
    [gui_interface_enhanced.py, optimized_scanner.py]
2026-03-22 feat: OCR improvements, white-bg crop, manual review report, false-positive fixes
    - crop_cards.py: batch white-margin trimmer using Color16410001.jpg dimensions
    (card region 782x1125 @ left=22 top=14, saves to google_drive_downloads_cropped/)
    - optimized_scanner.py:
    * Multi-pass OCR preprocessing: adds CLAHE, inverted Otsu, adaptive threshold
    variants so white-on-gray text (gray MTG frame) is covered alongside standard
    dark-on-light text
    * OCR noise rejection: rejects candidates with alpha ratio < 0.40 or total
    length > 160 chars (eliminates garbage like Color18060001 CNR/Oe noise)
    * Disable _extract_full_image_ocr_name fallback: reading card body text was
    resolving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
    [crop_cards.py, google_drive_scanner.py, optimized_scanner.py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]
2026-03-22 removing images
    [2.5mm spacer.stl, 25mm corner bracket (print 20).stl, 5mm spacer.stl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]
